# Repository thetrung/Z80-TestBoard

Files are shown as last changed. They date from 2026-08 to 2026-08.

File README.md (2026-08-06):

# Z80-TestBoard
Another test-NOP board for Z80 with NE555P.

### Note
A Strip-off version of Z80-Debugger but nothing rather than :
- Z80-NOP testboard for PLCC-44 package
- SOP28-DIP28 socket converter
- Tiny LED 5V power board 

### Preview 
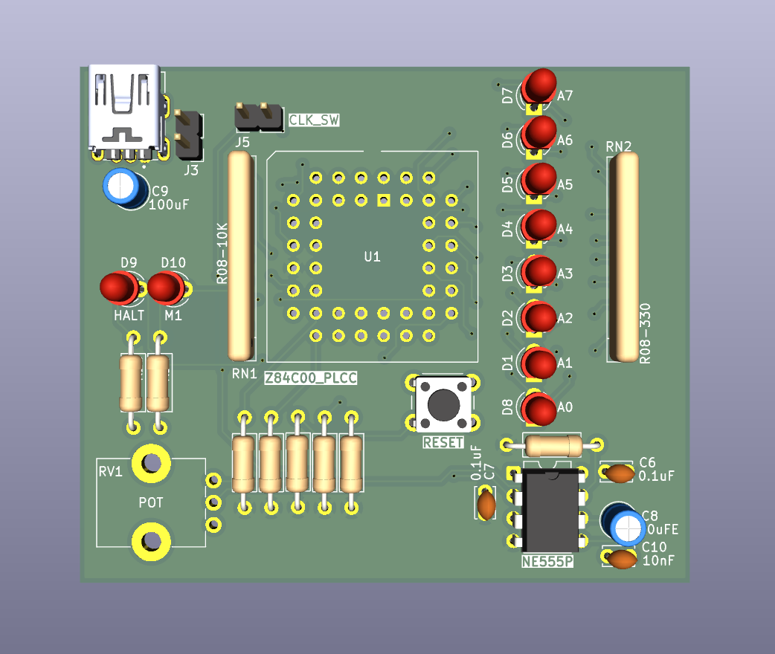
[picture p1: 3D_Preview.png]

### SilkScreen
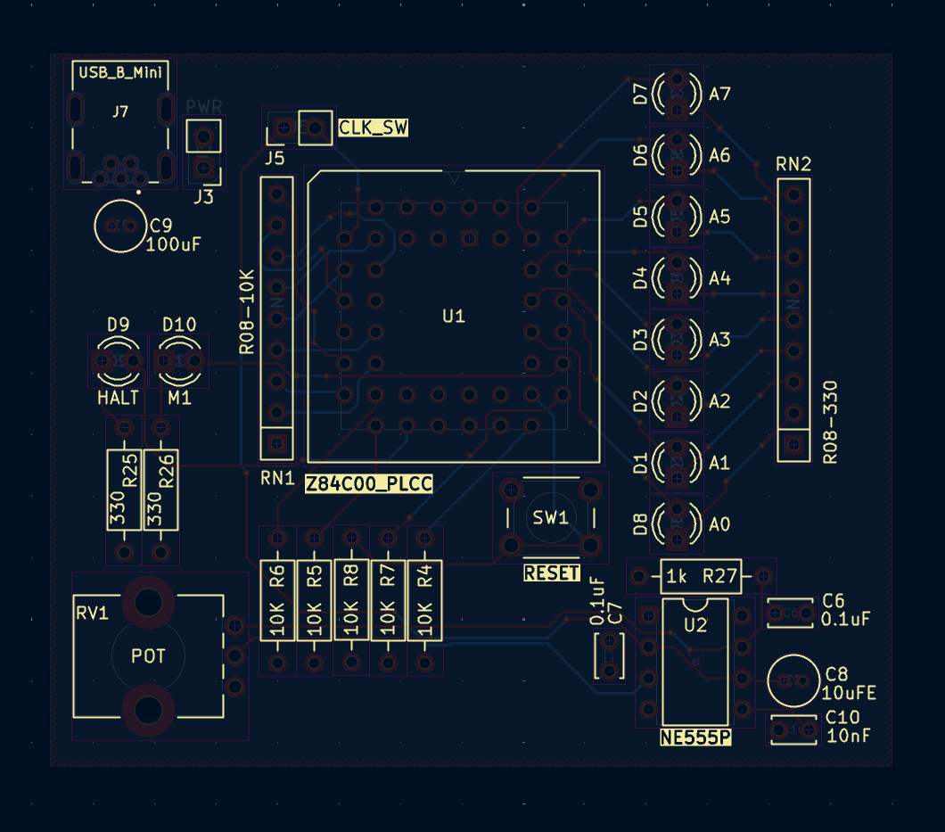
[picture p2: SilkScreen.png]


### Schematic 
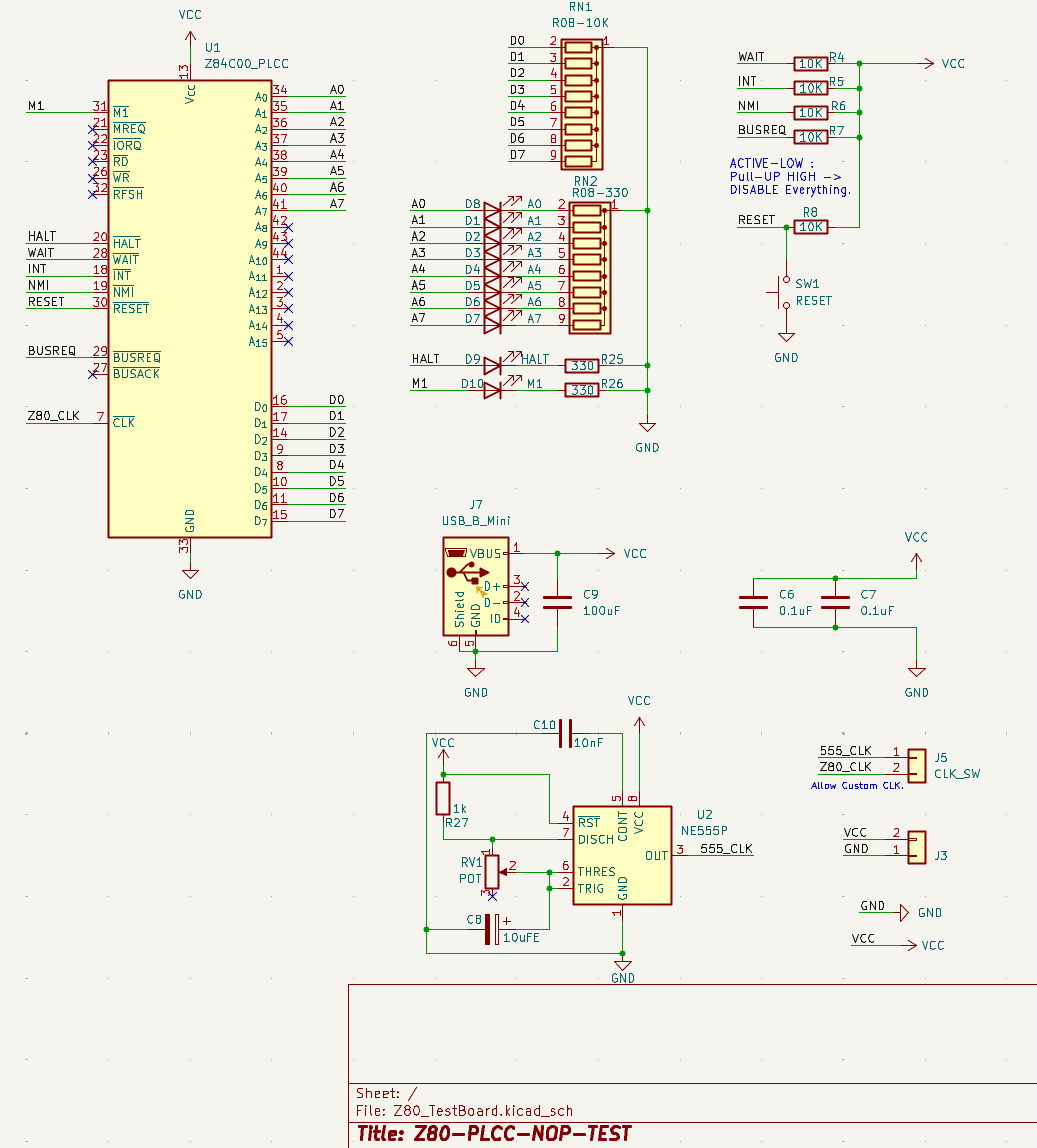
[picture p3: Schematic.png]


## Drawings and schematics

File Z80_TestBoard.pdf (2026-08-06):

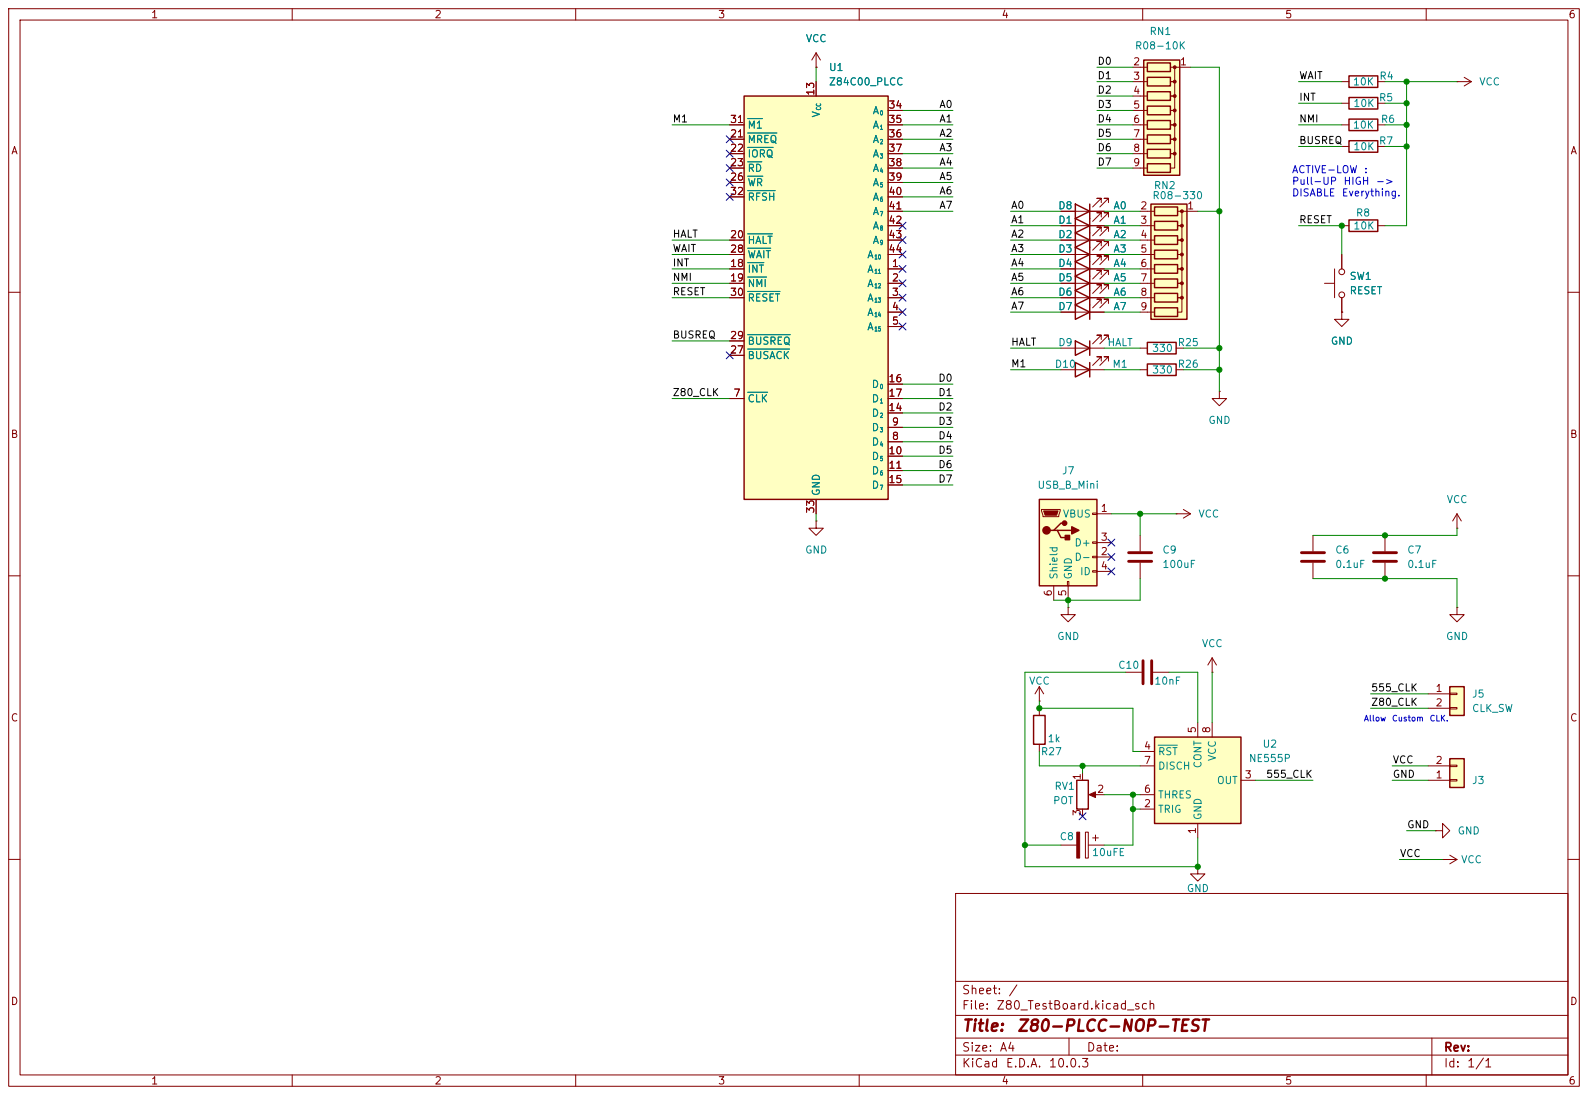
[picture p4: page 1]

INT 18 NMI 19 HALT 20 MREQ 21

Sheet: /
File: Z80_TestBoard.kicad_sch
Title: Z80-PLCC-NOP-TEST

Size: A4 | Rev:
KiCad E.D.A. 10.0.3 | Id: 1/1

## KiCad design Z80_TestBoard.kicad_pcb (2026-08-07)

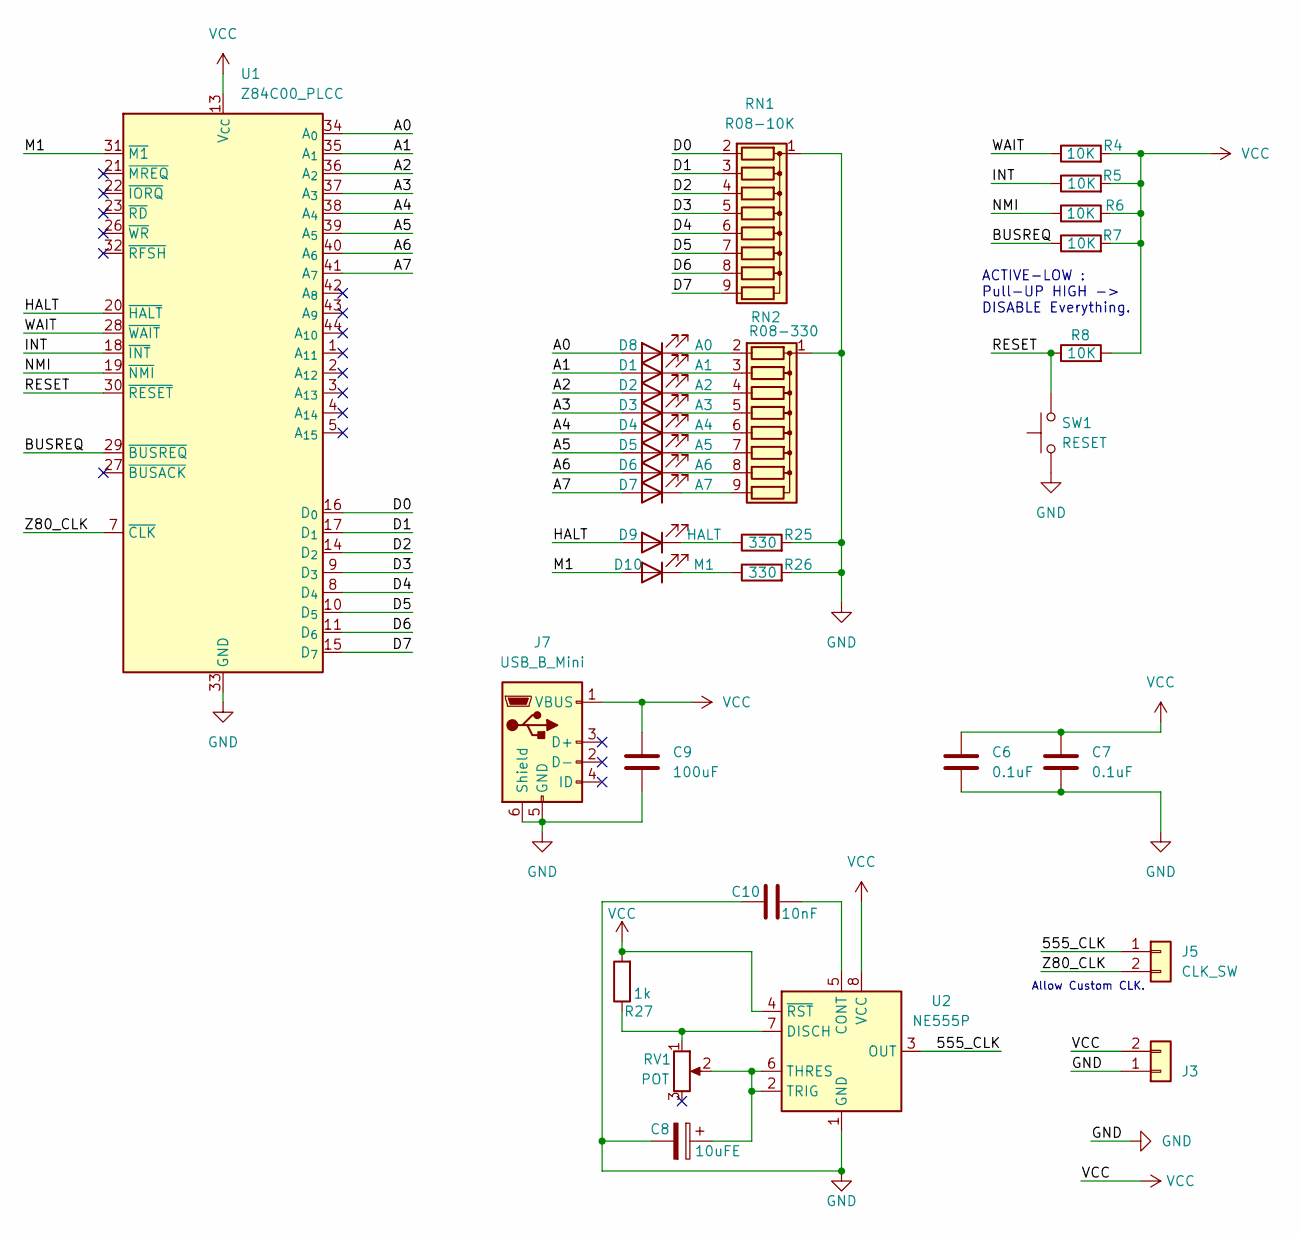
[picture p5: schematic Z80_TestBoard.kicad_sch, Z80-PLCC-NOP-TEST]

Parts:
C6, C7: 0.1uF; C_Disc_D3.4mm_W2.1mm_P2.50mm
C8: 10uFE; C_Radial_D4.0mm_H5.0mm_P1.50mm
C9: 100uF; C_Radial_D4.0mm_H5.0mm_P1.50mm
C10: 10nF; C_Disc_D3.4mm_W2.1mm_P2.50mm
D1: A1; LED_D3.0mm
D2: A2; LED_D3.0mm
D3: A3; LED_D3.0mm
D4: A4; LED_D3.0mm
D5: A5; LED_D3.0mm
D6: A6; LED_D3.0mm
D7: A7; LED_D3.0mm
D8: A0; LED_D3.0mm
D9: HALT; LED_D3.0mm
D10: M1; LED_D3.0mm
J3: PWR; PinHeader_1x02_P2.54mm_Vertical
J5: CLK_SW; PinHeader_1x02_P2.54mm_Vertical
J7: USB_B_Mini; USB_MINI_B_90_Angled
R4, R5, R6, R7, R8: 10K; R_Axial_DIN0207_L6.3mm_D2.5mm_P10.16mm_Horizontal
R25, R26: 330; R_Axial_DIN0207_L6.3mm_D2.5mm_P10.16mm_Horizontal
R27: 1k; R_Axial_DIN0207_L6.3mm_D2.5mm_P10.16mm_Horizontal
RN1: R08-10K; R_Array_SIP9
RN2: R08-330; R_Array_SIP9
RV1: POT; Potentiometer_Bourns_PTV09A-1_Single_Vertical
SW1: RESET; SW_PUSH_6mm
U1: Z84C00_PLCC; PLCC-44_THT-Socket
U2: NE555P; DIP-8_W7.62mm

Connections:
/Root/555_CLK: J5.1, U2.3 (OUT)
/Root/A0: D8.2 (A), U1.34 (A_{0})
/Root/A1: D1.2 (A), U1.35 (A_{1})
/Root/A2: D2.2 (A), U1.36 (A_{2})
/Root/A3: D3.2 (A), U1.37 (A_{3})
/Root/A4: D4.2 (A), U1.38 (A_{4})
/Root/A5: D5.2 (A), U1.39 (A_{5})
/Root/A6: D6.2 (A), U1.40 (A_{6})
/Root/A7: D7.2 (A), U1.41 (A_{7})
/Root/BUSREQ: R7.1, U1.29 (~BUSREQ)
/Root/D0: RN1.2 (R1), U1.16 (D_{0})
/Root/D1: RN1.3 (R2), U1.17 (D_{1})
/Root/D2: RN1.4 (R3), U1.14 (D_{2})
/Root/D3: RN1.5 (R4), U1.9 (D_{3})
/Root/D4: RN1.6 (R5), U1.8 (D_{4})
/Root/D5: RN1.7 (R6), U1.10 (D_{5})
/Root/D6: RN1.8 (R7), U1.11 (D_{6})
/Root/D7: RN1.9 (R8), U1.15 (D_{7})
/Root/HALT: D9.2 (A), U1.20 (~HALT)
/Root/INT: R5.1, U1.18 (~INT)
/Root/M1: D10.2 (A), U1.31 (~M1)
/Root/NMI: R6.1, U1.19 (~NMI)
/Root/RESET: R8.1, SW1.2, U1.30 (~RESET)
/Root/WAIT: R4.1, U1.28 (~WAIT)
/Root/Z80_CLK: J5.2, U1.7 (~CLK)
GND: C6.1, C7.1, C8.2, C9.1, C10.2, J3.1, J7.5 (GND), J7.6 (Shield), R25.2, R26.2, RN1.1 (common), RN2.1 (common), SW1.1, U1.33 (GND), U2.1 (GND)
unnamed: D1.1 (K), RN2.3 (R2)
unnamed: D2.1 (K), RN2.4 (R3)
unnamed: D3.1 (K), RN2.5 (R4)
unnamed: D4.1 (K), RN2.6 (R5)
unnamed: D5.1 (K), RN2.7 (R6)
unnamed: D6.1 (K), RN2.8 (R7)
unnamed: D7.1 (K), RN2.9 (R8)
unnamed: D8.1 (K), RN2.2 (R1)
unnamed: D9.1 (K), R25.1
unnamed: D10.1 (K), R26.1
unnamed: C10.1, U2.5 (CONT)
unnamed: R27.1, RV1.1, U2.7 (DISCH)
unnamed: C8.1, RV1.2, U2.2 (TRIG), U2.6 (THRES)
VCC: C6.2, C7.2, C9.2, J3.2, J7.1 (VBUS), R4.2, R5.2, R6.2, R7.2, R8.2, R27.2, U1.13 (V_{CC}), U2.4 (~RST), U2.8 (VCC)

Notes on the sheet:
ACTIVE-LOW : Pull-UP HIGH -> DISABLE Everything.
Allow Custom CLK.

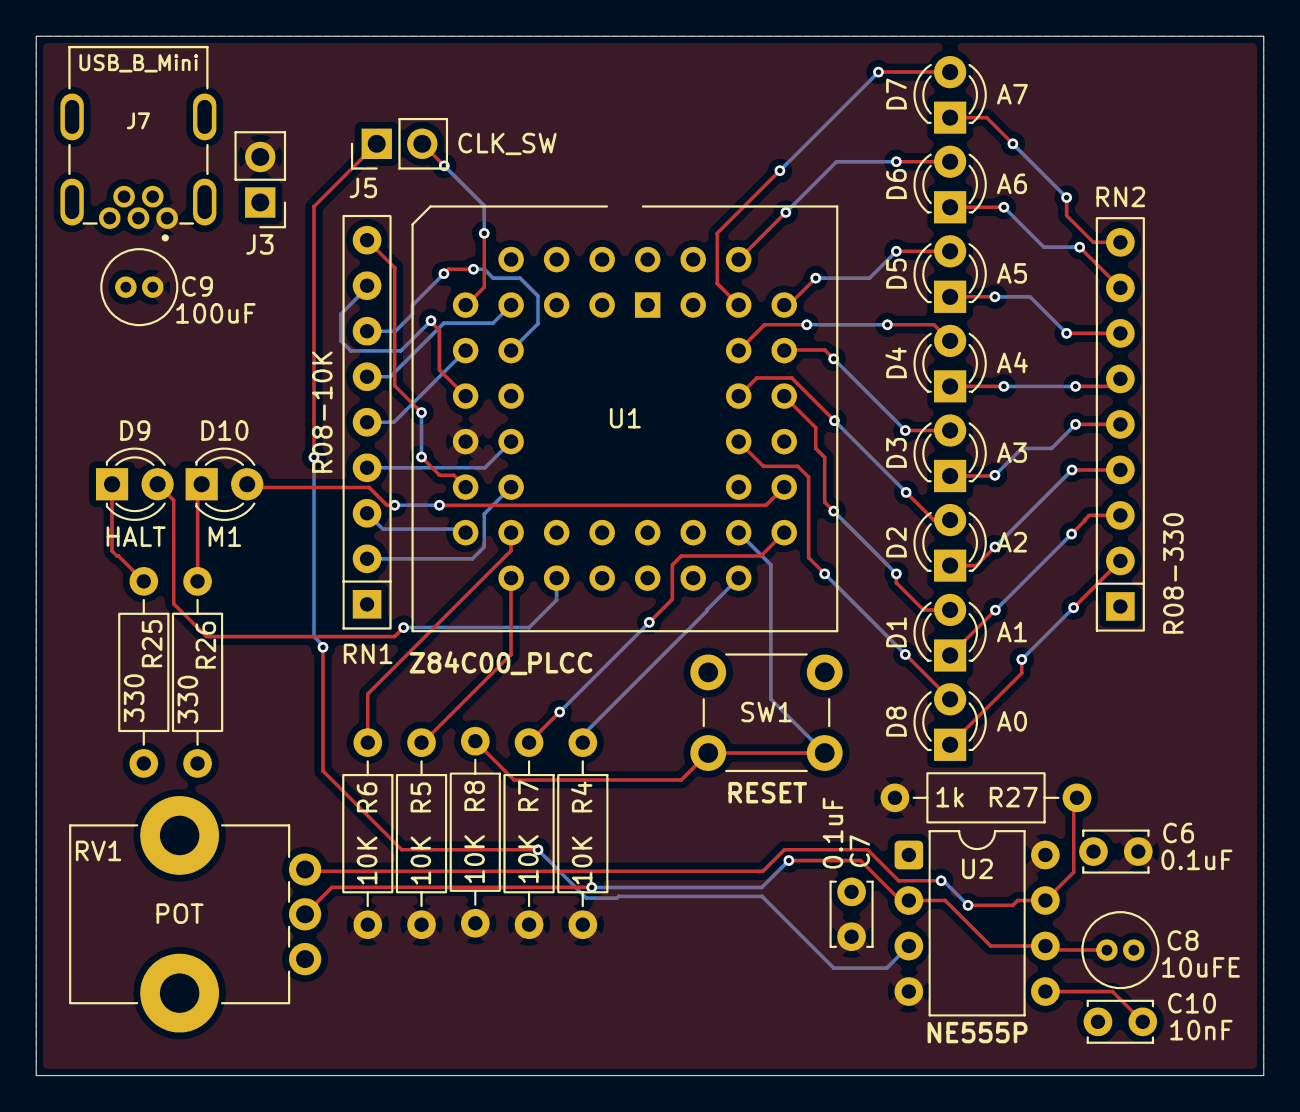
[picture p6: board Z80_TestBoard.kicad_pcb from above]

Board: 2 copper layers, 68.5 x 58.0 mm, 32 parts (0 on the bottom side), 40 nets.

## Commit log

2026-07-27 init Z80-TestBoard as Debugger Strip-off version.
    [Z80_TestBoard.kicad_pcb, Z80_TestBoard.kicad_sch]
2026-07-27 Export FAB config
    [Z80_TestBoard.kicad_pcb]
2026-08-06 Refine with NE555P + LED.
    [Z80_TestBoard.kicad_pcb, Z80_TestBoard.kicad_sch]
2026-08-06 finish routing/layout.
    [Z80_TestBoard.kicad_pcb, Z80_TestBoard.kicad_sch]
2026-08-06 add SOP28-DIP28 + LED-Board.
    [Z80_TestBoard.kicad_pcb, Z80_TestBoard.kicad_sch, led_board.kicad_sch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]
2026-08-06 production-ready panelized pcb.
    [Panelized_PCB.kicad_pcb, Z80_TestBoard.kicad_pcb]
2026-08-07 exclude sop28 + led boards.
    [Panelized_PCB.kicad_pcb, Z80_TestBoard.kicad_pcb, led_board.kicad_sch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]
